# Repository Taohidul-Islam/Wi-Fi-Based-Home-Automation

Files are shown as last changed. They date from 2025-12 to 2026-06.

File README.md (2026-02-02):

# Wi-Fi-Based-Home-Automation
<h2>This Board can turn any regular household electric switchboard into a smart Wi-Fi and Remote controlled switchboard.</h2>
<p>Here the board I designed is fail protected, meaning even if my electronic logic fails, the switchboard would work like a regular switchboard. The Automation Board is designed maintaining hierarchy. Meaning the Automation Board can only work only if the main switch from switch board is set to "on". In my logic I don't really turn anything "On". Everything is default "On" and "Off" by switchboard. I can just turn the things "Off" when the switch is "On" by triggering relay and turn the things back to it's default "On" position</p>
<p>N.B. IR remote control is currently unavailable and AC induction fan control channel can be faulty as it is not tested(will test soon).</p>

<P>Here are some screenshots of my PCB And Schematics</P>



Screenshot (96)
Screenshot (97)
Screenshot (98)
Screenshot (99)
Screenshot (116)
Screenshot (117)
Screenshot (118)
Screenshot (119)
Screenshot (120)

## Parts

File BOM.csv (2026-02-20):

Product | Value | Required Unit | Minimum Buying Unit | Buying Unit | Minimum buying unit Price(BDT) | Total Byuing Unit Price(Excluding Shipping)(BDT) | Total Byuing Unit Price(Excluding Shipping)(USD) | URL | Shipping From | Shipping Charge(BDT) | Shipping Charge(USD) | TOTAL COST AFTER SHIPPING(USD)
20 W Adapter | 220V AC--->5V DC | 1 | 1 | 1 | 1000 | 1000 | 8.09 | https://www.daraz.com.bd//products/i564440666-s2604870783.html?urlFlag=true | Daraz BD | 916 | 7.44 | 98.73
Relay Module | 5V Trigger, 10A 250VAC | 15 | 1 | 15 | 45 | 675 | 5.52 | https://www.daraz.com.bd//products/i319719106-s1469791008.html?urlFlag=true | Ali Express | 122.96 | 1.01
Fuse1 | 1A 5*20mm fast blow | 3 | set of 10 | 10 | 49 | 49 | 0.4 | https://www.daraz.com.bd//products/i444232118-s2128683451.html?urlFlag=true | Robotics BD | 55 | 0.45 | TOTAL COST AFTER SHIPPING(BDT)
Fuse2 | 2A 5*20mm fast blow | 12 | set of 10 | 20 | 49 | 98 | 0.8 | https://www.daraz.com.bd//products/i444232118-s2128683451.html?urlFlag=true | JLC PCB | 2166.41 | 17.73 | 12035.83
Fuse Holder | 5*20mm | 20 | set of10 | 20 | 49 | 49 | 0.4 | https://www.daraz.com.bd//products/i207310529-s1156909193.html?urlFlag=true | Printing Legion | 1596 | 13
PCB |  | 1 | 5 | 5 | 3580.46 | 3580.46 | 29.3 | https://trade.jlcpcb.com/checkout/payMethod/?unionSettleId=2c1f0726be4245ee9c5634154f041633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
Micro-Controller Board | ESP-32 Devkit k | 1 | 1 | 1 | 454 | 454 | 3.72 | https://www.daraz.com.bd//products/i324430221-s1552746576.html?urlFlag=true
Terminal Screw Blocks1 | P5mm 2pin | 12 | set of 5 | 15 | 37 | 111 | 0.91 | https://www.daraz.com.bd//products/i148914119-s1075120819.html?urlFlag=true
Terminal Screw Blocks2 | P5mm 3pin | 3 | set of 5 | 5 | 67 | 67 | 0.55 | https://www.daraz.com.bd//products/i295982132-s1309673742.html?urlFlag=true
Capacitor1 | 4.7uf-400V | 2 | set of 2 | 2 | 99 | 99 | 0.81 | https://www.daraz.com.bd//products/i458506660-s2198029867.html?urlFlag=true
Capacitor2 | 2.2uf-400V | 2 | set of 2 | 2 | 99 | 99 | 0.81 | https://www.daraz.com.bd//products/i535851508-s2573957824.html?urlFlag=true
Capacitor3 | 0.1uf-400V | 4 | set of 5 | 5 | 100 | 100 | 0.82 | https://www.daraz.com.bd//products/i128672154-s1048506248.html?urlFlag=true
Resistor1 | 220k 2W | 4 | set of 10 | 10 | 58 | 58 | 0.43 | https://www.daraz.com.bd//products/i286246768-s1284307192.html?urlFlag=true
Resistor2 | 2.2E 1/2W | 4 | set of 25 | 25 | 44 | 44 | 0.36 | https://www.daraz.com.bd//products/i143596114-s1067934018.html?urlFlag=true
Resistor3 | 220E 2W | 4 | set of 25 | 25 | 90 | 90 | 0.74 | https://www.daraz.com.bd//products/i225287965-s1170568856.html?urlFlag=true
Resistor4 | 2.2E 2W | 4 | Set of 20 | 20 | 120 | 120 | 0.98 | https://www.aliexpress.com/item/1005009970275128.html?mp=1
Varistor | 10D511k MOV | 4 | Set of 20 | 20 | 262 | 262 | 2.14 | https://www.aliexpress.com/item/1005010129610021.html?mp=1
Transistor Array | ULN2803A | 3 | 1 | 3 | 30 | 90 | 0.98 | https://store.roboticsbd.com/analog-ics-/1425-uln2803a-driver-ic-robotics-bangladesh.html
IR reciever module | vs1838B | 2 | 1 | 2 | 45 | 90 | 0.98 | https://www.daraz.com.bd//products/i227060729-s1171325043.html?urlFlag=true
Button | Push Buttons | 2 | Set of 3 | 3 | 44 | 44 | 0.36 | https://www.daraz.com.bd//products/i265246999-s1236615166.html?urlFlag=true
3D printing | Printing Legion Shipping | 1 | 1 | 1 | 0 | 0 | 0
TOTAL COST |  |  |  |  |  | 7179.46 | 59.1 |  |  | 4856.37 | 39.63

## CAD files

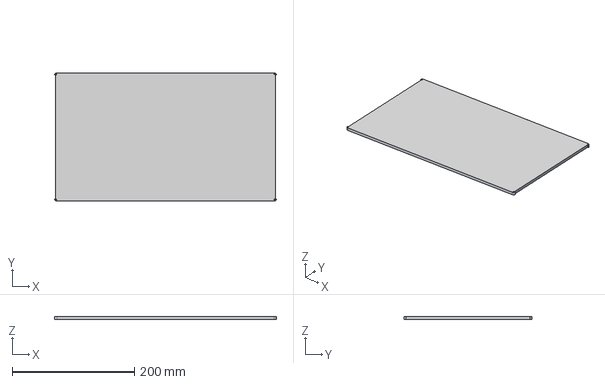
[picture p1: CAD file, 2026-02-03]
3D Model/HomeAutomationCaseLID3mm.step
363.0 x 210.0 x 5.00 mm

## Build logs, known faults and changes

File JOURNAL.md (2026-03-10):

<h1>Learned How to Design a PCB</h1>
<h2>December 11, 2025</h2>
<h3>Spent time: 2.8Hours</h3>
<p>Today through youtube, I learned how to design a PCB on Kikad and started building my first PCB design. Before I worked with breadboard circuitry but never designed a PCB. The one I am designing right now is not related to any project. It's just an tutorial piece. I am gonna make my main project PCB next day. The whole circuitry is on my head right now.
</p>




<h1>Completed my first PCB</h1>
<h2>December 12, 2025</h2>
<h3>Spent time:2.5Hours</h3>
<p>Today I completed my basic learning on building PCB and built an mini inverter PCB watching a tutorial. I leant how to make Gerber file and what to send to PCB manufacturer to manufacture my PCB. I hope from the next day, I can start building my project PCB.
</p>



<h1>Started making Schematics, researched on how to control AC.</h1>
<h2>December 13, 2025</h2>
<h3>Spent time: 4 Hours</h3>
<p> Today I started building my project PCB and done research on how to control AC average voltage with a TRIAC and ESP 32. I want to make a board which can be attached to any switch board and turn it into a smart switchboard. I want to also want to put an AC induction fan regulator. That's why I needed to learn about Triacs. But controlling AC voltage without a transformer is pretty hard ngl. Bought some things to practically learn about TRIACS.
</p>
Today I started building my project PCB and done research on how to control AC average voltage with a TRIAC and ESP 32. Bought some things to practically learn about TRIACS.




<h1>Finished doing Schematics</h1>
<h2>December 15, 2025</h2>
<h3>Spent time: 8 Hours</h3>
<p>I am journaling after two days as I was busy researching on how to control AC voltage via ESP 32. I couldn't get the TRIACS work so I switched to capacitor based step regulator. And after calculating my preferences and everything it took me a lot of time to do the schematics properly. I used a lot of labels as so many wirings might make it look messy. I switched to the capacitor method cause that is mostly traditional and many people used this kind off setup before me. I failed in controlling TRIACS on my demo model, so I gave up on it and switched to Capacitor based voltage control for AC induction FAN.</p>


<h1>Modified Schematics for safety</h1>
<h2>December 17, 2025</h2>
<h3>Spent time: 5 Hours</h3>
<p> Modified my final schematics to make it safe and sustainable against AC currents. Did a lot of research on making it safe and placed apropiate safety measures. I mainly added fused to each Channel so if anything inside the circuit failed, the board doesn't become a fire hazard. I also tried to put some place for Varistors for overvoltage protection. I want my board to be like this that if it fails due to any circumstances, the main switch board works perfectly fine.
 </p>




<h1>Started Designing PCB</h1>
<h2>December 18, 2025</h2>
<h3>Spent time: 2.5 Hours</h3>
<p>I started to design PCB today. First I assigned footprint to all of the components and started making PCB design. Researched how to put it on right place and decided where to put which components and started doing it. I wanted to complete routing today but couldn't due to limited time. I want to make it as compact as possible while maintaining the board design easy to understand and use, so anyone can do the wirings smoothly. So I needed to do put all screw terminal on a single side. But I did a silly mistake. In the 3d model, the screw hole was faced inward but I wanted it to be outward. Because the problem was with only 3D model and the routing can't be neater by putting the terminal to the expected side, I chose to keep the the 3D model as it is. While putting together the components, I just have to flip the terminals and that solves everything. I couldn't edit the 3d model as it was flipping the terminal and ruining my routing blueprint.</p>


<h1>Routed the PCB and Completed the hardware part.</h1>
<h2>December 22, 2025</h2>
<h3>Spent Time: 8 Hours</h3>
<p>Today I completed all my work of hardware on Kikad. I completed my PCB designing ensuring no error persisted. I checked it many times and found flaws until it showed no errors. I fixed all my errors and flaws and made it a workable PCB. I suffered a lot while choosing apropiate size for my paths in PCB, so I asked Gemini and gave him a list of what voltage and what current I want to use in what path, he suggested some width but I used a little bit more width than recommended because it gives a bit more headroom. While filling the PCB to GND, I kept all the AC traces away from the fill to prevent and leakage. Adjusting gap from pad to fill took a lot of time. I forgot that I increased the global distance from pad to fill a lot and was trying to adjust the distance in my tab so that wasn't working. After hours of not noticing it, I finally remembered that my global value was high. Then I decreased the global value and after that I could adjust my project value. Sometimes small silly things take more time than important things. Placing Via connection on right place with right radius and padding was also a bit tricky. I avoided via on high voltage AC side. I am very happy today.
</p>





<h1>Completed the coding part.</h1>
<h2>December 23, 2025</h2>
<h3>Spent time: 4 Hours</h3>
<p>
Today I wrote whole logic of my my system and used AI to code more efficiently. I tested all logics by lighting LED and ensuring signal is going properly wherever is need. The logic is like this,
Default, Switch On and Switch On means Low signal doing nothing. This will allow the NC gate of relay to work perfectly without interacting with the microcontroller.
Then when I press the switch On, microcontroller pin gives High signal which is transmitted to ULN transistor array that pulls the negative side of relay coil to ground thus activating the relay and turning the device off.
The fan regulator one is pretty complex. There is normal On off for fan with no Capacitor adjustment. but if you want, after turning off that normal on off button, you can turn on regulated switch buttons, which can channel electricity from 3 types of capacitor and resistor arrangements and controlling the fans speed within 3 Level.
After powering on the microcontroller, the microcontroller works as an Wi-Fi AP(Access Point) and after connecting to it's wifi network and going to certain IP, we can control the devices by toggling graphical toggle switch within phone browser. And there is a option to put home Wi-Fi SSID and password to connect it to home Wi-Fi and make it accessible from anyone in the Wi-Fi network. That is currently in Wi-Fi LAN but it is possible to put it to WAN through port forwarding if you have a real IP, that is a bit complicated and not suitable for everyone. I am planning to develop an application software to control it without typing IPs and using Browsers.
I currently didn't put any IR control code as I never worked with IR receiver. So I left a place on PCB to put IR receiver so after I learn about it, I can add it. This would make the thing more versatile by not depending only on WI-Fi Communications.
</p>


<h1>Enriched Journal Entries and BOM</h1>
<h2>January 14, 2026</h2>
<h3>Spent 2.5 Hours</h3>
<p>After getting reviewed by blueprint team, I needed to convert BOM from BDT to USD and to add more information on Journal. And for cost efficiency I needed to choose E-Post delivery on JLC PCB, SO I did that. Today I did nothing but edit BOM, rewriting some journal entries and take checkout screenshots.
I needed to convert USD to BDT and BDT simultaneously with cent accuracy, because I had a lot of components which had prices under a dollar. And due to BDT to USD price fluctuation and inflation, my prices decreased a little bit. I also added shipping charge separately site by site.</p>


<h1>Updated BOM again</h1>
<h2>February 1, 2026</h2>
<h3>Spent 1 Hour</h3>
<p>After getting reviewed again, I had to change the BOM again to remove the tools I mentioned there. So the cost got a bit low. I also got suggestion on how to make the schematics a bit better and was suggested to make a case for my PCB. But as per I has near to no experience in CAD, learning it would take time, and that's the thing I have least right now. As per my SSC examination(Comparable to O level) is coming close, my parents aren't allowing much screen time, so I couldn't make any larger changes. Changing schematics would require me to re-route the whole PCB, which would take hours. But as far I checked with many AI tools, my project seems to be functional. And as per I am new to PCB designing I might have broken some conventions while designing the PCB. Still I am trying if I can make a simple case.
</p>


<h1>Making Case For the PCB</h1>
<h2>February 2, 2026</h2>
<h3>Spent 4 Hours</h3>
<p>Today I somehow managed some time to make an case for my PCB in fusion 360. Learning this software was not that easy. Whatever, the hardest part was to figure out how to put the PCB from kikad into the case in fusion 360. After wandering for 30 minutes I figured it out and made a step file of my pcb from kikad first then imported that step into my fusion 360. now it looks pretty good. I also put screw holes to assemble it.
</p>
Screenshot (120)
Screenshot (119)
Screenshot (118)
Screenshot (117)
Screenshot (116)

<h1>Edited the case</h1>
<h2>March 11, 2026</h2>
<h3>Spent 2 Hours</h3>
<p>Today I added standoffs to my existing case to make my PCB secure inside the case. Previously I added just screw holes which might have been a trouble as the pins of pcb might get damaged by the case. Now it is fine with standoffs.</p>
Screenshot (124)

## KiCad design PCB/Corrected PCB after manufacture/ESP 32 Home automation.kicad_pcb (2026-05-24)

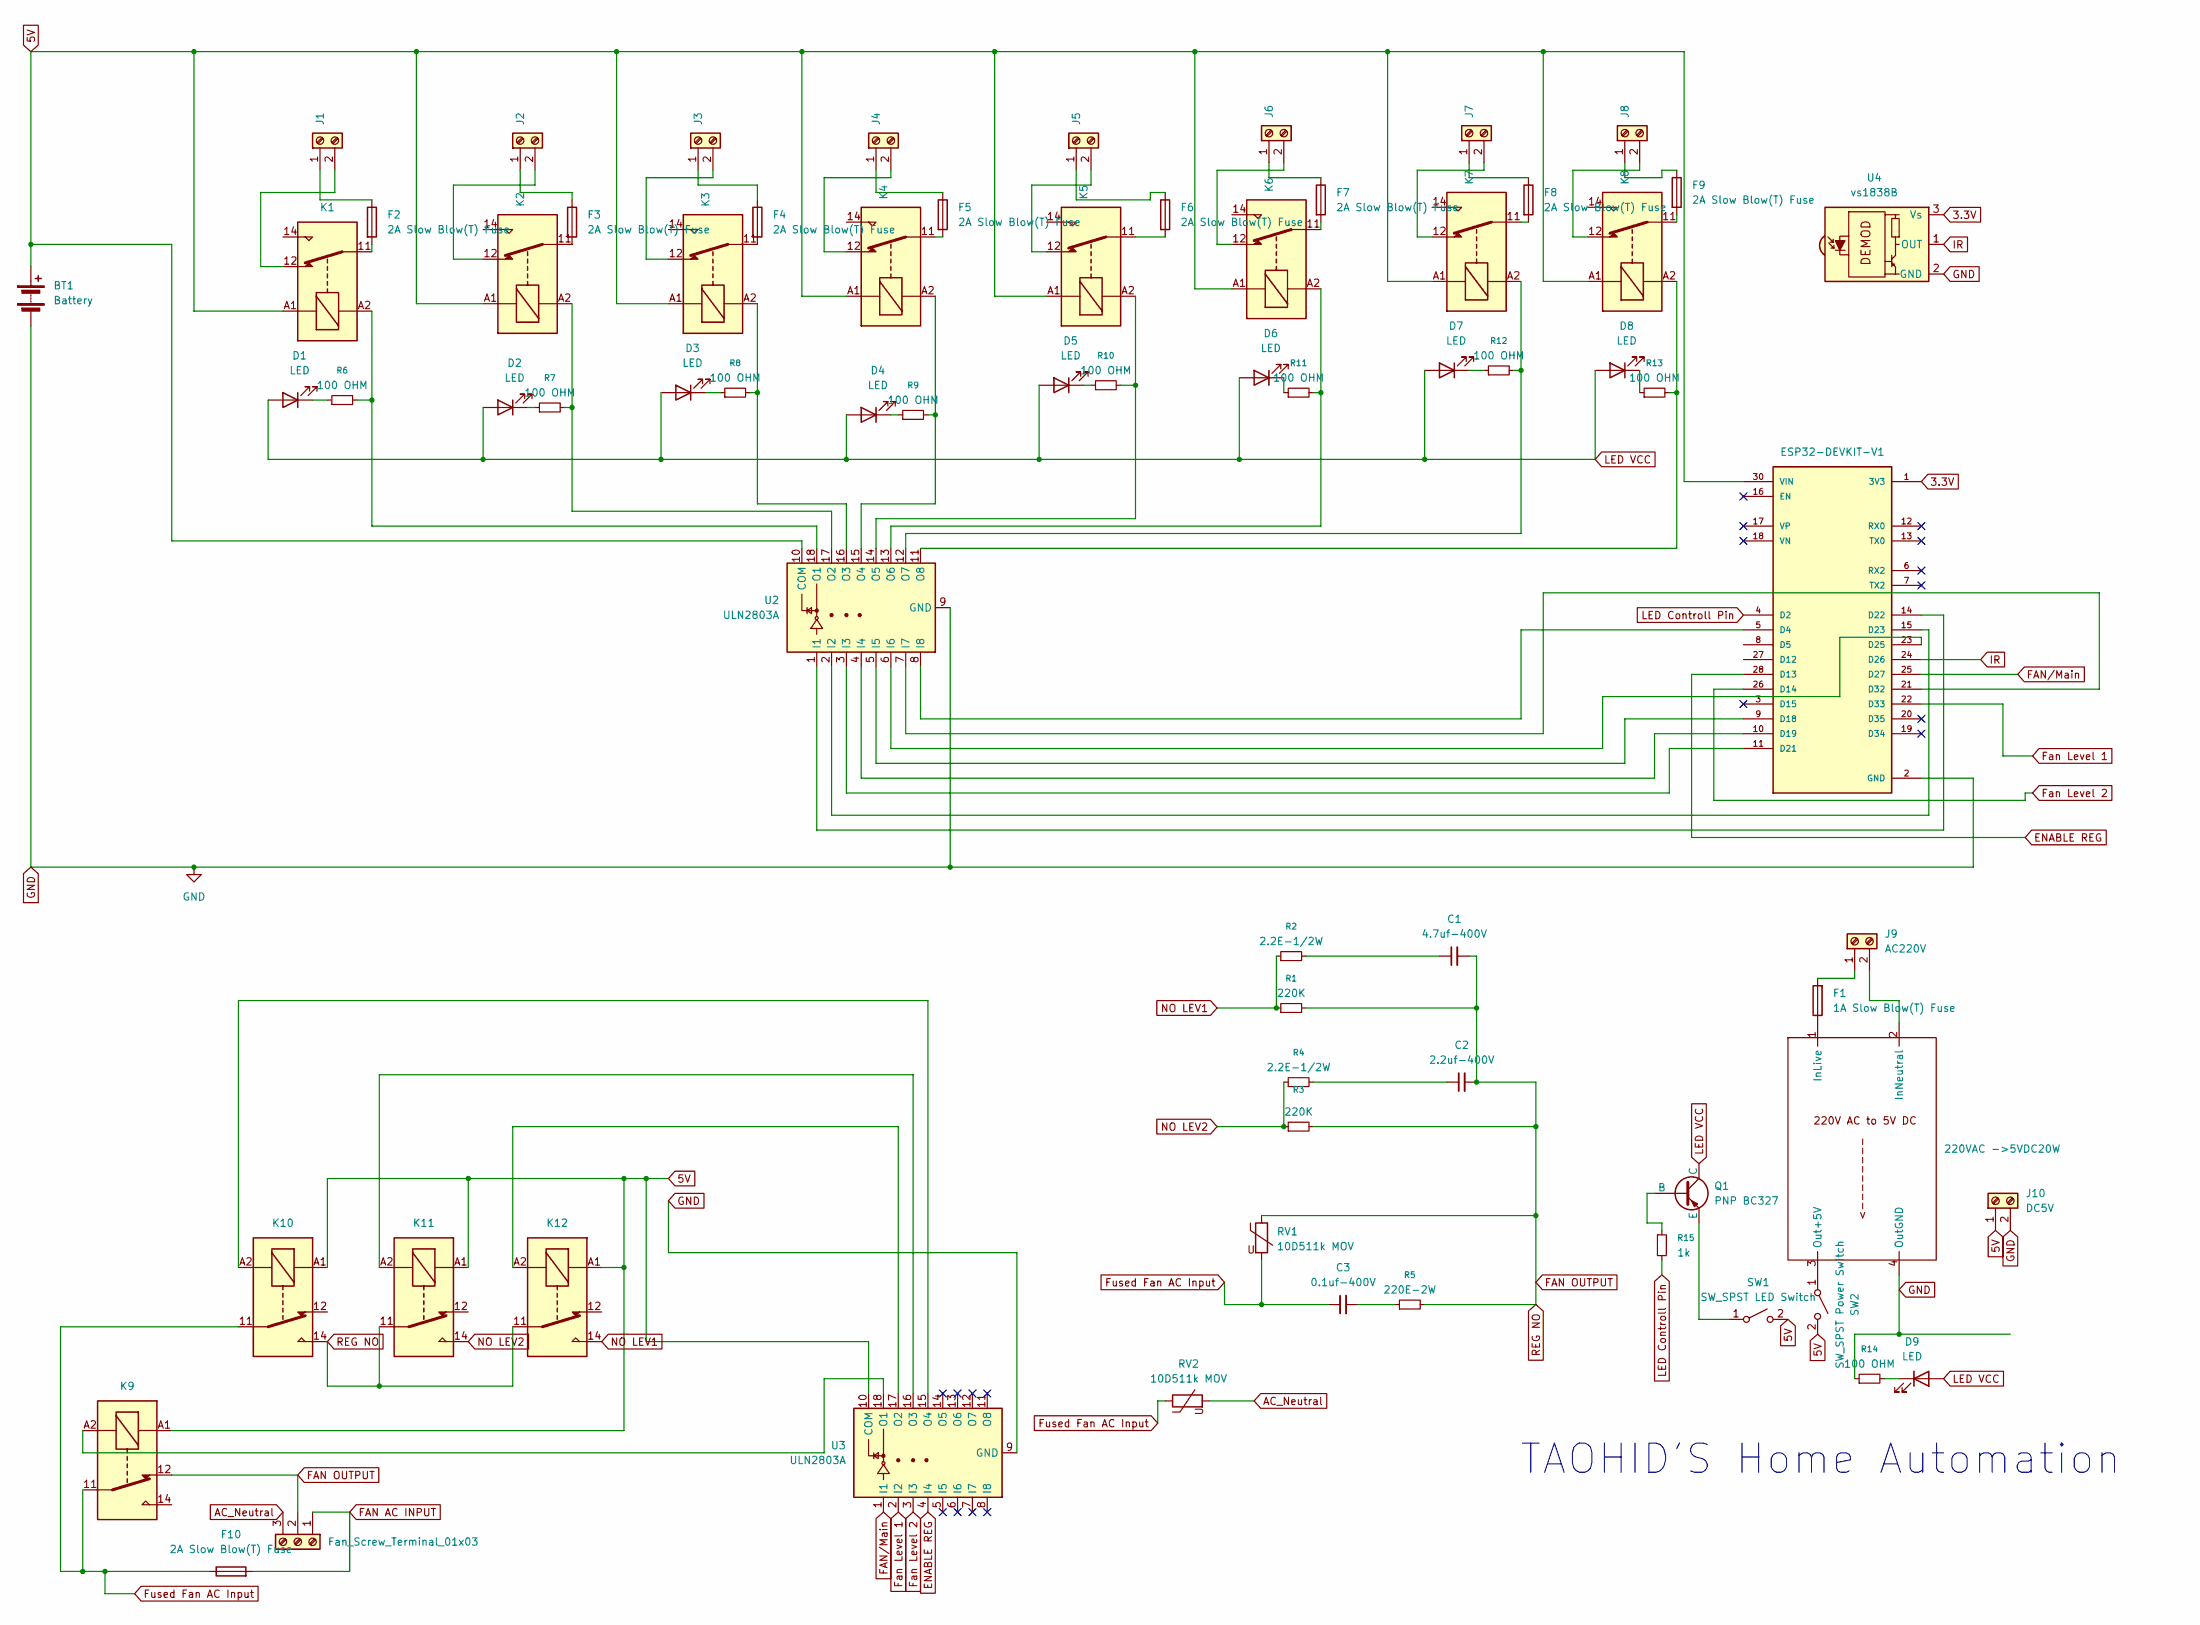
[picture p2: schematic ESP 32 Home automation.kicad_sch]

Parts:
Adapter/Charger1: 220VAC ->5VDC20W; ACtoDC power Adapter. 220V to 5V
BT1: Battery; TerminalBlock_MaiXu_MX126-5.0-02P_1x02_P5.00mm
C1: 4.7uf-400V; C_Rect_L32.0mm_W15.0mm_P27.00mm
C2: 2.2uf-400V; C_Rect_L27.0mm_W9.0mm_P22.00mm
C3: 0.1uf-400V; C_Rect_L13.0mm_W6.5mm_P7.50mm_P10.00mm
D1, D2, D3, D4, D5, D6, D7, D8, D9: LED; LED_D5.0mm
F1: 1A Slow Blow(T) Fuse; Fuseholder_Littelfuse_100_series_5x20mm
F2, F3, F4, F5, F6, F7, F8, F9, F10: 2A Slow Blow(T) Fuse; Fuseholder_Littelfuse_100_series_5x20mm
J1, J2, J3, J4, J5, J6, J7, J8: Screw_Terminal_01x02; TerminalBlock_Phoenix_MKDS-1,5-2-5.08_1x02_P5.08mm_Horizont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
J9: AC220V; TerminalBlock_Phoenix_MKDS-1,5-2-5.08_1x02_P5.08mm_Horizont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
J10: DC5V; TerminalBlock_Phoenix_MKDS-1,5-2-5.08_1x02_P5.08mm_Horizont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
J11: Fan_Screw_Terminal_01x03; TerminalBlock_Phoenix_MKDS-1,5-3-5.08_1x03_P5.08mm_Horizont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
K1, K2, K3, K4, K5, K6, K7, K8, K9, K10, K11, K12: JQC-3FF-005-1Z; Relay_SPDT_Hongfa_JQC-3FF_0XX-1Z
Q1: PNP BC327; TO-92_Inline
R1, R3: 220K; R_Axial_DIN0309_L9.0mm_D3.2mm_P20.32mm_Horizontal
R2, R4: 2.2E-1/2W; R_Axial_DIN0309_L9.0mm_D3.2mm_P20.32mm_Horizontal
R5: 220E-2W; R_Axial_DIN0309_L9.0mm_D3.2mm_P20.32mm_Horizontal
R6, R7, R8, R9, R10, R11, R12, R13, R14: 100 OHM; R_Axial_DIN0207_L6.3mm_D2.5mm_P7.62mm_Horizontal
R15: 1k; R_Axial_DIN0207_L6.3mm_D2.5mm_P7.62mm_Horizontal
RV1, RV2: 10D511k MOV; RV_Disc_D12mm_W7.5mm_P7.5mm
SW1: SW_SPST LED Switch; TerminalBlock_Phoenix_MKDS-1,5-2_1x02_P5.00mm_Horizontal
SW2: SW_SPST Power Switch; TerminalBlock_Phoenix_MKDS-1,5-2_1x02_P5.00mm_Horizontal
U1: ESP32-DEVKIT-V1; MODULE_ESP32_DEVKIT_V1; PARTREV N/A
U2, U3: ULN2803A; DIP-18_W7.62mm_Socket_LongPads
U4: vs1838B; Vishay_MOLD-3Pin

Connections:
3.3V: U1.1 (3V3), U4.3 (Vs)
5V: BT1.1 (+), J10.1, K1.A1, K2.A1, K3.A1, K4.A1, K5.A1, K6.A1, K7.A1, K8.A1, K9.A1, K10.A1, K11.A1, K12.A1, SW1.2 (B), SW2.2 (B), U1.30 (VIN), U2.10 (COM), U3.10 (COM)
AC_Neutral: J11.3, RV2.2; also elsewhere on the board
ENABLE REG: U1.28 (D13), U3.4 (I4)
FAN AC INPUT: F10.2, J11.1
FAN/Main: U1.25 (D27), U3.1 (I1)
Fan Level 1: U1.22 (D33), U3.2 (I2)
Fan Level 2: U1.26 (D14), U3.3 (I3)
Fused Fan AC Input: C3.1, F10.1, K9.11, K10.11, RV1.2, RV2.1
GND: Adapter/Charger1.4 (OutGND), BT1.2 (-), J10.2, R14.1, U1.2 (GND), U1.29 (GND), U2.9 (GND), U3.9 (GND), U4.2 (GND)
IR: U1.24 (D26), U4.1 (OUT)
LED Controll Pin: R15.2, U1.4 (D2)
LED VCC: D1.2 (A), D2.2 (A), D3.2 (A), D4.2 (A), D5.2 (A), D6.2 (A), D7.2 (A), D8.2 (A), D9.2 (A), Q1.1 (C)
NO LEV1: K12.14, R1.1, R2.1
NO LEV2: K11.14, R3.1, R4.1
unnamed: Adapter/Charger1.1 (InLive), F1.1
unnamed: Adapter/Charger1.2 (InNeutral), J9.2
unnamed: Adapter/Charger1.3 (Out+5V), SW2.1 (A)
unnamed: C1.1, R2.2
unnamed: C2.1, R4.2
unnamed: C3.2, R5.1
unnamed: D2.1 (K), R7.1
unnamed: D3.1 (K), R8.1
unnamed: D4.1 (K), R9.1
unnamed: D5.1 (K), R10.1
unnamed: D6.1 (K), R11.1
unnamed: D7.1 (K), R12.1
unnamed: D8.1 (K), R13.1
unnamed: D9.1 (K), R14.2
unnamed: F2.2, K1.11
unnamed: F3.2, K2.11
unnamed: F4.2, K3.11
unnamed: F5.2, K4.11
unnamed: F6.2, K5.11
unnamed: F7.2, K6.11
unnamed: F8.2, K7.11
unnamed: F9.2, K8.11
unnamed: F2.1, J1.1
unnamed: J1.2, K1.12
unnamed: F3.1, J2.1
unnamed: J2.2, K2.12
unnamed: F4.1, J3.1
unnamed: J3.2, K3.12
unnamed: F5.1, J4.1
unnamed: J4.2, K4.12
unnamed: F6.1, J5.1
unnamed: J5.2, K5.12
unnamed: F7.1, J6.1
unnamed: J6.2, K6.12
unnamed: F8.1, J7.1
unnamed: J7.2, K7.12
unnamed: F9.1, J8.1
unnamed: J8.2, K8.12
unnamed: F1.2, J9.1
unnamed: Q1.2 (B), R15.1
unnamed: Q1.3 (E), SW1.1 (A)
unnamed: U1.5 (D4), U2.8 (I8)
unnamed: U1.9 (D18), U2.5 (I5)
unnamed: U1.10 (D19), U2.4 (I4)
unnamed: U1.11 (D21), U2.3 (I3)
unnamed: U1.14 (D22), U2.1 (I1)
unnamed: U1.15 (D23), U2.2 (I2)
unnamed: U1.23 (D25), U2.6 (I6)
unnamed: U1.21 (D32), U2.7 (I7)
unnamed: K2.A2, R7.2, U2.17 (O2)
unnamed: K3.A2, R8.2, U2.16 (O3)
unnamed: K4.A2, R9.2, U2.15 (O4)
unnamed: K5.A2, R10.2, U2.14 (O5)
unnamed: K6.A2, R11.2, U2.13 (O6)
unnamed: K7.A2, R12.2, U2.12 (O7)
unnamed: K8.A2, R13.2, U2.11 (O8)
unnamed: K9.A2, U3.18 (O1)
unnamed: K12.A2, U3.17 (O2)
unnamed: K11.A2, U3.16 (O3)
unnamed: K10.A2, U3.15 (O4)

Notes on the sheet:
TAOHID'S Home Automation

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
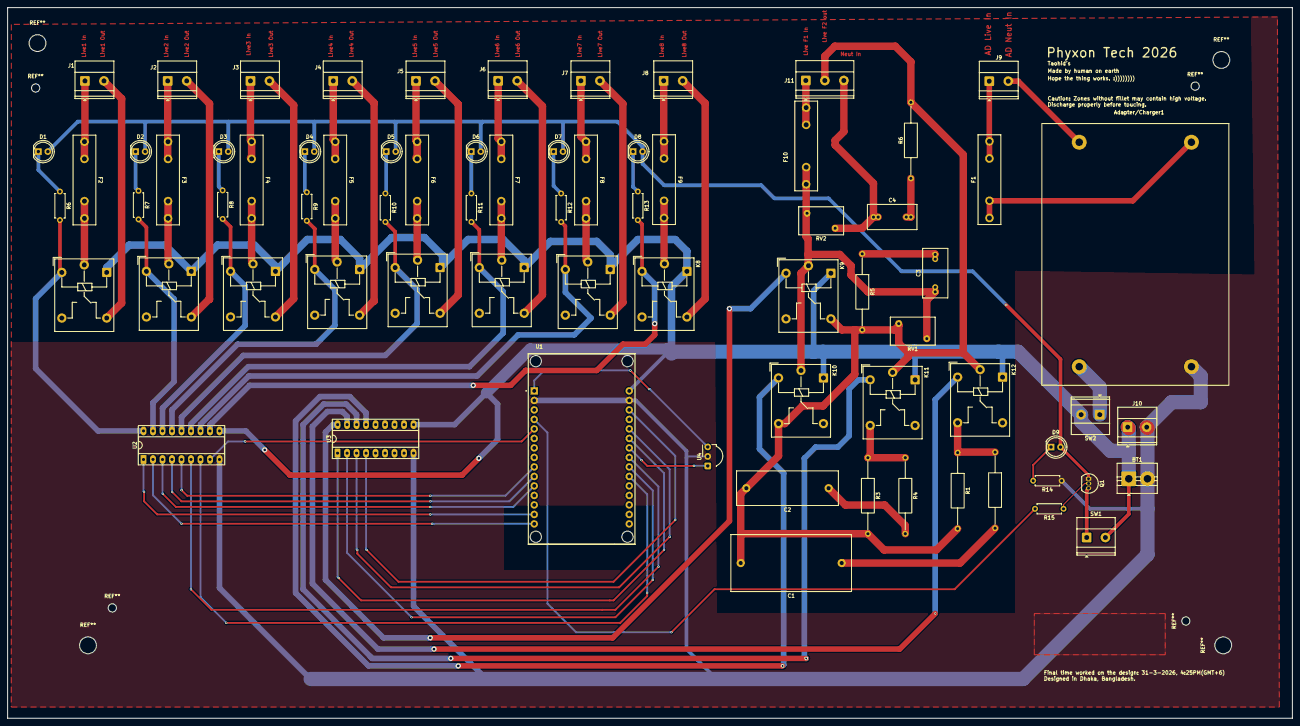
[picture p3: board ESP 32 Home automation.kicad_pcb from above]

Board: 2 copper layers, 343.5 x 190.0 mm, 73 parts (0 on the bottom side), 79 nets.

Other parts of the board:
C4: 0.1uf-400V; C_Rect_L13.0mm_W6.5mm_P7.50mm_P10.00mm
R6#2: 100 OHM; R_Axial_DIN0207_L6.3mm_D2.5mm_P7.62mm_Horizontal

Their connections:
AC_Neutral: C4.1; also elsewhere on the board

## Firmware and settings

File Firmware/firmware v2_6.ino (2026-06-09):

/*
 * ============================================================
 *   Wi-Fi Based Automation Firmware v2.6
 *   by Taohid | Phyxon Tech
 *   Board: DOIT ESP32 DevKit V1
 *   Change Line 113 and 504 as per your credentials
 * ============================================================
 *
 * Required Libraries (install via Arduino Library Manager):
 *   - IRremote (by Armin Joachimsmeyer) >= 4.x
 *   - U8g2 (by oliver)
 *   - ArduinoJson (by Benoit Blanchon) >= 6.x
 *   - NewPing (by Tim Eckel)
 *
 * Changes in v2.6:
 *   - IR I button: decrease people count (min 0)
 *   - IR J button: increase people count
 *   - IR K button: factory reset (moved from J)
 * ============================================================
 * GPIO TABLE:
 *   RELAY_1=22, RELAY_2=23, RELAY_3=21, RELAY_4=19
 *   RELAY_5=18, RELAY_6=25, RELAY_7=32, RELAY_8=4
 *   RESET_PIN=15  (INPUT_PULLUP, pull to GND = factory reset)
 *   LED_CTRL=2    (PNP driver, LOW=LEDs ON)
 *   LED_BTN=14    (OUTPUT HIGH after boot, pull to GND = toggle LED)
 *   IR_RECV=26
 *   OLED_SDA=27, OLED_SCL=33
 *   SONAR1_TRIG=5,  SONAR1_ECHO=34  (outside doorframe)
 *   SONAR2_TRIG=12, SONAR2_ECHO=35  (inside doorframe)
 * ============================================================
 */

#include <WiFi.h>
#include <WebServer.h>
#include <Preferences.h>
#include <ESPmDNS.h>
#include <HTTPClient.h>
#include <HTTPUpdate.h>
#include <ArduinoJson.h>
#include <Wire.h>
#include <U8g2lib.h>
#include <IRremote.hpp>
#include <NewPing.h>
#include <time.h>
#include <math.h>

// ============================================================
// GPIO
// ============================================================
#define RELAY_1      22
#define RELAY_2      23
#define RELAY_3      21
#define RELAY_4      19
#define RELAY_5      18
#define RELAY_6      25
#define RELAY_7      32
#define RELAY_8       4
#define RESET_PIN    15
#define LED_CTRL      2
#define LED_BTN      14
#define IR_RECV_PIN  26
#define OLED_SDA     27
#define OLED_SCL     33
#define SONAR1_TRIG   5
#define SONAR1_ECHO  34
#define SONAR2_TRIG  12
#define SONAR2_ECHO  35
#define SONAR_MAX_DIST 200

// ============================================================
// IR CODES
// ============================================================
#define IR_1     0x01
#define IR_2     0x02
#define IR_3     0x03
#define IR_4     0x04
#define IR_5     0x05
#define IR_6     0x06
#define IR_7     0x07
#define IR_8     0x08
#define IR_9     0x09
#define IR_0     0x00
#define IR_PWR   0x12
#define IR_A     0x14
#define IR_B     0x10
#define IR_C     0x16
#define IR_D     0x0C
#define IR_E     0x49
#define IR_H     0x0F
#define IR_I     0x45
#define IR_J     0x56
#define IR_K     0x5C
#define IR_OK    0x0E
#define IR_UP    0x1B
#define IR_DOWN  0x1F
#define IR_LEFT  0x1E
#define IR_RIGHT 0x1A
#define IR_SLASH 0x0B

// ============================================================
// NETWORK
// ============================================================
const char* ap_ssid     = "ESP32_SmartSwitch";
const char* ap_password = "12345678";
IPAddress ap_ip(192, 168, 4, 1);
IPAddress ap_gateway(192, 168, 4, 1);
IPAddress ap_subnet(255, 255, 255, 0);
IPAddress static_ip(192, 168, 0, 200);
IPAddress gateway_ip(192, 168, 0, 1);
IPAddress subnet_ip(255, 255, 255, 0);
IPAddress dns_ip(192, 168, 0, 1);

const char* OTA_HOST   = "YOUR SERVER IP HERE";
const int   OTA_PORT   = 8080;
const char* FW_VERSION = "2.6";

// ============================================================
// OLED — SH1106 1.3" SW I2C, U8G2_R2 = 180° for upside-down mount
// ============================================================
U8G2_SH1106_128X64_NONAME_F_SW_I2C u8g2(U8G2_R2, OLED_SCL, OLED_SDA, U8X8_PIN_NONE);

// ============================================================
// SONARS
// ============================================================
NewPing sonar1(SONAR1_TRIG, SONAR1_ECHO, SONAR_MAX_DIST);
NewPing sonar2(SONAR2_TRIG, SONAR2_ECHO, SONAR_MAX_DIST);

// ============================================================
// SCREEN IDs
// ============================================================
#define SCREEN_WEATHER   0
#define SCREEN_EYES      1
#define SCREEN_CLOCK     2
#define SCREEN_ANALOG    3
#define SCREEN_OVERVIEW  4
#define SCREEN_WEBUI     5
#define SCREEN_PEOPLE    6
#define SCREEN_COUNT     7

// ============================================================
// EYE SYSTEM
// ============================================================
#define LEX    34
#define REX    94
#define EYE_CY 30
#define EW     28
#define EH     36
#define ER     10

enum Emotion {
  EMO_FRONT=0, EMO_BLINK, EMO_SLEEP, EMO_HAPPY,
  EMO_MAD, EMO_CRY, EMO_CONFUSED, EMO_TIRED,
  EMO_WIDE, EMO_NIGHT, EMO_COUNT
};

Emotion currentEmo = EMO_FRONT;
unsigned long emoStart = 0;
int emoSeqIdx = 0;
float pupilX = 0, pupilY = 0, pupilTX = 0, pupilTY = 0;
unsigned long lastPupilPick = 0;

Emotion emoSequence[] = {
  EMO_FRONT, EMO_BLINK, EMO_FRONT, EMO_HAPPY,
  EMO_FRONT, EMO_BLINK, EMO_MAD,   EMO_FRONT,
  EMO_CRY,   EMO_FRONT, EMO_TIRED, EMO_BLINK,
  EMO_WIDE,  EMO_FRONT, EMO_CONFUSED, EMO_FRONT,
  EMO_SLEEP, EMO_FRONT, EMO_NIGHT, EMO_FRONT
};
const int emoSeqLen = 20;
unsigned long emoDurations[] = {
  2500,400,2000,1500,2000,400,1800,1500,
  2000,1500,1800,400,1200,2000,2000,2000,
  2500,1500,2000,2000
};

// ============================================================
// WEATHER
// ============================================================
struct Weather {
  String description;
  float  temp=0; int humidity=0;
  bool   isCloudy=false; bool fetched=false;
};
Weather wx;
unsigned long lastWeatherFetch=0;
float cloudOffset=0; unsigned long lastCloudUpdate=0;
#define WEATHER_INTERVAL 600000UL

// ============================================================
// GLOBAL STATE
// ============================================================
WebServer   server(80);
Preferences preferences;

bool relayStates[8]      = {false};
bool ledState             = true;
const int relayPins[8]   = {RELAY_1,RELAY_2,RELAY_3,RELAY_4,RELAY_5,RELAY_6,RELAY_7,RELAY_8};

bool   useAPMode    = true;
String storedSSID   = "";
String storedPass   = "";

bool   darkMode         = true;
String weatherCity      = "Dhaka";
int    timezone_offset  = 6;

bool   autoOffEnabled[8]      = {false};
int    peopleCount             = 1;
bool   sonarActive             = false;
bool   autoOffedByPresence[8] = {false};

int    autoOffDelaySec  = 0;   // seconds to wait before turning off on zero count
int    autoOnDelaySec   = 0;   // seconds to wait before turning on when count goes 0→1+

// Timer state for delayed actions
bool          pendingOff        = false;
unsigned long pendingOffTime    = 0;
bool          pendingOn         = false;
unsigned long pendingOnTime     = 0;

bool   screenEnabled[SCREEN_COUNT];
int    screenInterval       = 5;
bool   autoSwitch           = true;
int    currentScreen        = SCREEN_EYES;
int    fixedScreen          = SCREEN_EYES;
int    screenBeforeWebUI    = SCREEN_EYES;

bool   oledInWebUI  = false;
int    oledTab      = 0;
int    oledCursor   = 0;

bool   showingStartupIP = true;
unsigned long startupIPTime = 0;
#define STARTUP_IP_DURATION 10000UL

unsigned long lastOLEDDraw   = 0;
#define OLED_REFRESH_MS 30

unsigned long lastScreenSwitch = 0;
unsigned long ledBtnLastPress  = 0;
#define DEBOUNCE_MS 200

int    sonarDetectDist  = 60;    // cm — configurable from web settings
int    sonarConfirmWin  = 1500;  // ms — tightened for 15cm doorframe

// Alternating fire state
int    sonarTurn        = 0;     // 0=fire S1, 1=fire S2
unsigned long lastSonarFire = 0;
#define SONAR_FIRE_INTERVAL 50   // ms between alternate pings

unsigned long sonar1TrigTime=0, sonar2TrigTime=0;
bool sonar1Triggered=false, sonar2Triggered=false;

// Cooldown after crossing
#define SONAR_COOLDOWN 2500
unsigned long lastCrossingTime=0;

// Live state for web dots
bool sonar1Live=false, sonar2Live=false;
unsigned long sonar1LiveTime=0, sonar2LiveTime=0;
#define SONAR_LIVE_DISPLAY_MS 400

// FreeRTOS sonar task handle
TaskHandle_t sonarTaskHandle = NULL;
// Mutex to protect shared sonar state accessed from both cores
portMUX_TYPE sonarMux = portMUX_INITIALIZER_UNLOCKED;

String otaStatusMsg = "";

// ============================================================
// FORWARD DECLARATIONS
// ============================================================
void initGPIO(); void applyAllStates();
void startAPMode(); void connectToWiFi();
void setupRoutes(); void factoryReset();
void fetchWeather(); void syncNTP(); void doOTAUpdate();
void sonarTask(void* pvParameters);
void handleLEDButton(); void handleIR();
void drawOLED();
void drawWeather(); void drawEyes(); void drawDigitalClock();
void drawAnalogClock(); void drawOverview(); void drawWebUI();
void drawPeople(); void drawStartupIP();
void nextEnabledScreen(); void centreStr(const char* s, int y);
String buildHomePage(); String buildSettingsPage(); String buildStatusJSON();
void saveSettings(); void loadSettings();
void fillEye(int cx,int cy,int w,int h,int r);
void drawPupil(int cx,int cy,int px,int py,int pr);
void drawEyeWithLid(int cx,int cy,float close,bool upperOnly);
void drawEmo_Front(); void drawEmo_Blink(float t); void drawEmo_Sleep();
void drawEmo_Happy(); void drawEmo_Mad(); void drawEmo_Cry(float t);
void drawEmo_Confused(); void drawEmo_Tired(); void drawEmo_Wide(); void drawEmo_Night();
void drawSunIcon(int cx,int cy); void drawCloudIcon(int cx,int cy);
void handleToggle(); void handleToggleLed(); void handleSaveWiFi();
void handleUseAP(); void handleSaveSettings(); void handleSetPeople();

// ============================================================
// SETUP
// ============================================================
void setup() {
  Serial.begin(115200); delay(500);
  Serial.println("\n=== Phyxon Home Automation v2.1 ===");

  pinMode(LED_BTN, OUTPUT);
  digitalWrite(LED_BTN, HIGH);

  Wire.begin(OLED_SDA, OLED_SCL);
  u8g2.begin();
  u8g2.setContrast(220);

  preferences.begin("phyxon", false);
  loadSettings();
  for(int i=0;i<SCREEN_COUNT;i++)
    screenEnabled[i] = preferences.getBool(("se"+String(i)).c_str(), true);

  initGPIO();
  applyAllStates();

  sonarActive = false;
  for(int i=0;i<8;i++) if(autoOffEnabled[i]) { sonarActive=true; break; }

  // Always start sonar task on Core 0 (for people counting even without auto-off)
  xTaskCreatePinnedToCore(sonarTask, "SonarTask", 4096, NULL, 1, &sonarTaskHandle, 0);

  IrReceiver.begin(IR_RECV_PIN, DISABLE_LED_FEEDBACK);

  if(!useAPMode && storedSSID.length()>0) connectToWiFi();
  else startAPMode();

  if(MDNS.begin("phyxon")) Serial.println("mDNS: phyxon.local");
  setupRoutes();
  server.begin();

  if(WiFi.getMode()==WIFI_STA && WiFi.status()==WL_CONNECTED) {
    syncNTP(); fetchWeather();
  }

  showingStartupIP = true;
  startupIPTime    = millis();
  emoStart         = millis();
  randomSeed(millis());
  Serial.println("=== Ready ===");
}

// ============================================================
// LOOP
// ============================================================
void loop() {
  server.handleClient();
  handleLEDButton();
  handleIR();

  // Delayed auto-off: fire if timer expired and count still zero
  if(pendingOff && peopleCount == 0 &&
     millis() - pendingOffTime >= (unsigned long)(autoOffDelaySec * 1000)) {
    pendingOff = false;
    for(int i=0;i<8;i++) if(autoOffEnabled[i] && relayStates[i]) {
      relayStates[i]=false; digitalWrite(relayPins[i],HIGH);
      preferences.putBool(("r"+String(i)).c_str(),false);
      autoOffedByPresence[i]=true;
    }
    Serial.println("Delayed OFF executed");
  }
  // Cancel pending off if someone came back
  if(pendingOff && peopleCount > 0) {
    pendingOff = false;
    Serial.println("Pending OFF cancelled, room occupied");
  }

  // Delayed auto-on: fire if timer expired and count still > 0
  if(pendingOn && peopleCount > 0 &&
     millis() - pendingOnTime >= (unsigned long)(autoOnDelaySec * 1000)) {
    pendingOn = false;
    for(int i=0;i<8;i++) if(autoOffedByPresence[i]) {
      relayStates[i]=true; digitalWrite(relayPins[i],LOW);
      preferences.putBool(("r"+String(i)).c_str(),true);
      autoOffedByPresence[i]=false;
    }
    Serial.println("Delayed ON executed");
  }
  // Cancel pending on if everyone left again
  if(pendingOn && peopleCount == 0) {
    pendingOn = false;
    Serial.println("Pending ON cancelled, room empty");
  }

  if(millis()-lastOLEDDraw > OLED_REFRESH_MS) {
    lastOLEDDraw=millis(); drawOLED();
  }

  if(autoSwitch && !oledInWebUI && !showingStartupIP) {
    if(millis()-lastScreenSwitch > (unsigned long)(screenInterval*1000)) {
      lastScreenSwitch=millis(); nextEnabledScreen();
    }
  }

  if(WiFi.status()==WL_CONNECTED && millis()-lastWeatherFetch>WEATHER_INTERVAL)
    fetchWeather();

  if(digitalRead(RESET_PIN)==LOW) { delay(50); if(digitalRead(RESET_PIN)==LOW) factoryReset(); }

  if(showingStartupIP && millis()-startupIPTime>STARTUP_IP_DURATION)
    showingStartupIP=false;
}

// ============================================================
// GPIO
// ============================================================
void initGPIO() {
  for(int i=0;i<8;i++) pinMode(relayPins[i],OUTPUT);
  pinMode(RESET_PIN,INPUT_PULLUP);
  pinMode(LED_CTRL,OUTPUT);
}
void applyAllStates() {
  for(int i=0;i<8;i++) digitalWrite(relayPins[i], relayStates[i]?LOW:HIGH);
  digitalWrite(LED_CTRL, ledState?LOW:HIGH);
}

// ============================================================
// WIFI
// ============================================================
void startAPMode() {
  WiFi.mode(WIFI_AP);
  WiFi.softAPConfig(ap_ip,ap_gateway,ap_subnet);
  WiFi.softAP(ap_ssid,ap_password);
  Serial.println("AP @ 192.168.4.1");
}
void connectToWiFi() {
  WiFi.mode(WIFI_STA);
  WiFi.config(static_ip,gateway_ip,subnet_ip,dns_ip);
  WiFi.begin(storedSSID.c_str(),storedPass.c_str());
  Serial.print("Connecting");
  int att=0;
  while(WiFi.status()!=WL_CONNECTED && att<30) { delay(500); Serial.print("."); att++; }
  if(WiFi.status()==WL_CONNECTED) Serial.println("\nConnected: "+WiFi.localIP().toString());
  else { Serial.println("\nFailed, fallback AP"); startAPMode(); }
}

// ============================================================
// SETTINGS
// ============================================================
void loadSettings() {
  storedSSID     = preferences.getString("ssid","");
  storedPass     = preferences.getString("pass","");
  useAPMode      = preferences.getBool("useAP",true);
  ledState       = preferences.getBool("led",true);
  darkMode       = preferences.getBool("dark",true);
  weatherCity    = preferences.getString("city","Dhaka");
  timezone_offset= preferences.getInt("tz",6);
  peopleCount    = preferences.getInt("people",1);
  autoSwitch     = preferences.getBool("autoSw",true);
  screenInterval = preferences.getInt("scrInt",5);
  fixedScreen    = preferences.getInt("fixedScr",SCREEN_EYES);
  currentScreen  = autoSwitch ? SCREEN_EYES : fixedScreen;
  sonarDetectDist= preferences.getInt("snrDist", 60);
  sonarConfirmWin= preferences.getInt("snrWin",  2000);
  autoOffDelaySec= preferences.getInt("aoDelay", 0);
  autoOnDelaySec = preferences.getInt("aonDelay",0);
  for(int i=0;i<8;i++) {
    relayStates[i]   = preferences.getBool(("r"+String(i)).c_str(),false);
    autoOffEnabled[i]= preferences.getBool(("ao"+String(i)).c_str(),false);
  }
}
void saveSettings() {
  preferences.putBool("useAP",useAPMode); preferences.putBool("led",ledState);
  preferences.putBool("dark",darkMode);   preferences.putString("city",weatherCity);
  preferences.putInt("tz",timezone_offset); preferences.putInt("people",peopleCount);
  preferences.putBool("autoSw",autoSwitch); preferences.putInt("scrInt",screenInterval);
  preferences.putInt("fixedScr",fixedScreen);
  preferences.putInt("snrDist", sonarDetectDist);
  preferences.putInt("snrWin",  sonarConfirmWin);
  preferences.putInt("aoDelay", autoOffDelaySec);
  preferences.putInt("aonDelay",autoOnDelaySec);
  for(int i=0;i<8;i++) {
    preferences.putBool(("r"+String(i)).c_str(),relayStates[i]);
    preferences.putBool(("ao"+String(i)).c_str(),autoOffEnabled[i]);
  }
  for(int i=0;i<SCREEN_COUNT;i++)
    preferences.putBool(("se"+String(i)).c_str(),screenEnabled[i]);
}
void factoryReset() {
  Serial.println("FACTORY RESET");
  preferences.clear(); delay(500); ESP.restart();
}

// ============================================================
// NTP
// ============================================================
void syncNTP() {
  configTime(timezone_offset*3600,0,"pool.ntp.org","time.nist.gov");
  Serial.print("NTP sync");
  struct tm t; int tr=0;
  while(!getLocalTime(&t)&&tr<20){delay(500);Serial.print(".");tr++;}
  Serial.println(getLocalTime(&t)?" OK":" FAIL");
}

// ============================================================
// WEATHER
// ============================================================
void fetchWeather() {
  if(WiFi.status()!=WL_CONNECTED) return;
  lastWeatherFetch=millis();
  HTTPClient http;
  String url="http://api.openweathermap.org/data/2.5/weather?q="+
             weatherCity+"&appid=YOURAPIKEYHERE&units=metric";
  http.begin(url); http.setTimeout(8000);
  if(http.GET()==200) {
    String payload=http.getString();
    JsonDocument doc;
    if(!deserializeJson(doc,payload)) {
      wx.temp       =doc["main"]["temp"].as<float>();
      wx.humidity   =doc["main"]["humidity"].as<int>();
      wx.description=doc["weather"][0]["description"].as<String>();
      wx.isCloudy   =(String(doc["weather"][0]["main"].as<const char*>())!="Clear");
      wx.fetched    =true;
      Serial.printf("Weather:%.1fC %d%% %s\n",wx.temp,wx.humidity,wx.description.c_str());
    }
  }
  http.end();
}

// ============================================================
// OTA (manual trigger from web button)
// ============================================================
void doOTAUpdate() {
  if(WiFi.status()!=WL_CONNECTED) { otaStatusMsg="No WiFi"; return; }
  otaStatusMsg="Checking server...";
  HTTPClient http;
  http.begin("http://"+String(OTA_HOST)+":"+String(OTA_PORT)+"/version");
  int code=http.GET();
  if(code!=200) { otaStatusMsg="Server unreachable (HTTP "+String(code)+")"; http.end(); return; }
  String sv=http.getString(); sv.trim(); http.end();
  if(sv==String(FW_VERSION)) { otaStatusMsg="Already up to date (v"+String(FW_VERSION)+")"; return; }
  otaStatusMsg="Updating to v"+sv+"...";
  saveSettings();
  String binUrl="http://"+String(OTA_HOST)+":"+String(OTA_PORT)+"/firmware.bin";
  WiFiClient client;
  t_httpUpdate_return ret=httpUpdate.update(client, binUrl);
  switch(ret) {
    case HTTP_UPDATE_FAILED:    otaStatusMsg="Failed: "+httpUpdate.getLastErrorString(); break;
    case HTTP_UPDATE_NO_UPDATES:otaStatusMsg="No updates found"; break;
    case HTTP_UPDATE_OK:        otaStatusMsg="Updated! Rebooting..."; break;
  }
}

// ============================================================
// LED BUTTON
// ============================================================
void handleLEDButton() {
  pinMode(LED_BTN,INPUT);
  bool pressed=(digitalRead(LED_BTN)==LOW);
  pinMode(LED_BTN,OUTPUT); digitalWrite(LED_BTN,HIGH);
  if(pressed && millis()-ledBtnLastPress>DEBOUNCE_MS) {
    ledBtnLastPress=millis();
    ledState=!ledState;
    digitalWrite(LED_CTRL,ledState?LOW:HIGH);
    preferences.putBool("led",ledState);
  }
}
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

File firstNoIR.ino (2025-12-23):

#include <WiFi.h>
#include <WebServer.h>
#include <Preferences.h>
#include <ESPmDNS.h>

// GPIO Pin Definitions
#define RELAY_1 22
#define RELAY_2 23
#define RELAY_3 21
#define RELAY_4 19
#define RELAY_5 18
#define RELAY_6 25
#define RELAY_7 32
#define RELAY_8 4

#define FAN_ON 27
#define FAN_LEV1 33
#define FAN_LEV2 14
#define FAN_LEV3 13

#define RESET_PIN 15  // Reset to AP mode button (pull to GND)

// AP Mode Configuration
const char* ap_ssid = "ESP32_SmartSwitch";
const char* ap_password = "12345678";
IPAddress ap_ip(192, 168, 4, 1);
IPAddress ap_gateway(192, 168, 4, 1);
IPAddress ap_subnet(255, 255, 255, 0);

// Static IP Configuration for Home WiFi
IPAddress static_ip(192, 168, 0, 200); // Change this to your desired static IP
IPAddress gateway(192, 168, 0, 1);     // Your router's gateway
IPAddress subnet(255, 255, 255, 0);
IPAddress dns(192, 168, 0, 1);

// Global Variables
WebServer server(80);
Preferences preferences;

bool relayStates[8] = {true, true, true, true, true, true, true, true}; // Default ON
bool fanOnState = true;  // Default ON
int fanLevel = 0;        // 0=OFF, 1=LEV1, 2=LEV2, 3=LEV3
bool useAPMode = true;
String storedSSID = "";
String storedPassword = "";
unsigned long lastStatusPrint = 0;

// GPIO Pins Array
const int relayPins[8] = {RELAY_1, RELAY_2, RELAY_3, RELAY_4, RELAY_5, RELAY_6, RELAY_7, RELAY_8};

void setup() {
  Serial.begin(115200);
  delay(1000);
  
  Serial.println("\n\n========================================");
  Serial.println("   ESP32 Smart Switchboard v1.0");
  Serial.println("========================================\n");
  
  // Initialize Preferences
  preferences.begin("wifi-config", false);
  storedSSID = preferences.getString("ssid", "");
  storedPassword = preferences.getString("password", "");
  useAPMode = preferences.getBool("useAP", true);
  
  Serial.println("Stored SSID: " + (storedSSID.length() > 0 ? storedSSID : "None"));
  Serial.println("Use AP Mode: " + String(useAPMode ? "Yes" : "No"));
  
  // Load saved states
  for(int i = 0; i < 8; i++) {
    relayStates[i] = preferences.getBool(("relay" + String(i)).c_str(), true);
  }
  fanOnState = preferences.getBool("fanOn", true);
  fanLevel = preferences.getInt("fanLevel", 0);
  
  // Initialize GPIO Pins
  initGPIO();
  applyAllStates();
  
  Serial.println("\n--- Network Configuration ---");
  
  // Start WiFi
  if (!useAPMode && storedSSID.length() > 0) {
    connectToWiFi();
  } else {
    startAPMode();
  }
  
  // Setup Web Server Routes
  setupRoutes();
  server.begin();
  
  Serial.println("\n========================================");
  Serial.println("   System Ready!");
  Serial.println("========================================\n");
}

void loop() {
  server.handleClient();
  
  // Print status every 10 seconds if in WiFi mode
  if(WiFi.getMode() == WIFI_STA && millis() - lastStatusPrint > 10000) {
    lastStatusPrint = millis();
    Serial.println("\n--- Status Update ---");
    Serial.print("WiFi Connected: ");
    Serial.println(WiFi.status() == WL_CONNECTED ? "YES" : "NO");
    Serial.print("IP Address: ");
    Serial.println(WiFi.localIP());
    Serial.print("Access at: http://");
    Serial.println(WiFi.localIP());
    Serial.print("Or via: http://smartswitch.local");
    Serial.println("\n-------------------\n");
  }
  
  // Check if reset button is pressed (pulled to GND)
  if(digitalRead(RESET_PIN) == LOW) {
    delay(50); // Debounce
    if(digitalRead(RESET_PIN) == LOW) {
      Serial.println("Reset button pressed! Switching to AP mode...");
      
      // Save AP mode preference
      preferences.putBool("useAP", true);
      
      delay(500);
      ESP.restart();
    }
  }
}

void initGPIO() {
  // Initialize all relay pins
  for(int i = 0; i < 8; i++) {
    pinMode(relayPins[i], OUTPUT);
  }
  
  // Initialize fan control pins
  pinMode(FAN_ON, OUTPUT);
  pinMode(FAN_LEV1, OUTPUT);
  pinMode(FAN_LEV2, OUTPUT);
  pinMode(FAN_LEV3, OUTPUT);
  
  // Initialize reset button with internal pull-up
  pinMode(RESET_PIN, INPUT_PULLUP);
}

void applyAllStates() {
  // Apply relay states (ON = LOW, OFF = HIGH)
  for(int i = 0; i < 8; i++) {
    digitalWrite(relayPins[i], relayStates[i] ? LOW : HIGH);
  }
  
  // Apply fan states
  digitalWrite(FAN_ON, fanOnState ? LOW : HIGH);
  
  if(fanOnState) {
    // Fan is ON, disable all levels
    digitalWrite(FAN_LEV1, LOW);
    digitalWrite(FAN_LEV2, LOW);
    digitalWrite(FAN_LEV3, LOW);
  } else {
    // Fan is OFF, apply level if selected
    applyFanLevel();
  }
}

void applyFanLevel() {
  // First, turn off all levels with delay
  digitalWrite(FAN_LEV1, LOW);
  delay(50);
  digitalWrite(FAN_LEV2, LOW);
  delay(50);
  digitalWrite(FAN_LEV3, LOW);
  delay(50);
  
  // Then turn on the selected level (if any)
  if(fanLevel == 1) {
    digitalWrite(FAN_LEV1, HIGH);
  } else if(fanLevel == 2) {
    digitalWrite(FAN_LEV2, HIGH);
  } else if(fanLevel == 3) {
    digitalWrite(FAN_LEV3, HIGH);
  }
}

void startAPMode() {
  Serial.println("Starting AP Mode...");
  WiFi.mode(WIFI_AP);
  WiFi.softAPConfig(ap_ip, ap_gateway, ap_subnet);
  WiFi.softAP(ap_ssid, ap_password);
  
  Serial.print("AP IP Address: ");
  Serial.println(WiFi.softAPIP());
  Serial.println("Connect to WiFi: " + String(ap_ssid));
  Serial.println("Navigate to: http://192.168.4.1");
}

void connectToWiFi() {
  Serial.println("Connecting to WiFi...");
  Serial.println("SSID: " + storedSSID);
  WiFi.mode(WIFI_STA);
  WiFi.config(static_ip, gateway, subnet, dns);
  WiFi.begin(storedSSID.c_str(), storedPassword.c_str());
  
  int attempts = 0;
  while (WiFi.status() != WL_CONNECTED && attempts < 30) {
    delay(500);
    Serial.print(".");
    attempts++;
  }
  
  if (WiFi.status() == WL_CONNECTED) {
    Serial.println("\nConnected to WiFi!");
    Serial.print("Static IP Address: ");
    Serial.println(WiFi.localIP());
    Serial.print("Gateway: ");
    Serial.println(WiFi.gatewayIP());
    Serial.print("Subnet: ");
    Serial.println(WiFi.subnetMask());
    Serial.print("DNS: ");
    Serial.println(WiFi.dnsIP());
    
    // Setup mDNS
    if(MDNS.begin("smartswitch")) {
      Serial.println("mDNS started: http://smartswitch.local");
    }
  } else {
    Serial.println("\n❌ Failed to connect to WiFi!");
    Serial.println("Reason: " + String(WiFi.status()));
    Serial.println("Falling back to AP Mode...");
    
    // Clear saved credentials and switch to AP mode
    preferences.putBool("useAP", true);
    startAPMode();
  }
}

void setupRoutes() {
  server.on("/", HTTP_GET, handleRoot);
  server.on("/config", HTTP_GET, handleConfig);
  server.on("/savewifi", HTTP_POST, handleSaveWiFi);
  server.on("/useap", HTTP_POST, handleUseAP);
  server.on("/toggle", HTTP_POST, handleToggle);
  server.on("/fanon", HTTP_POST, handleFanOn);
  server.on("/fanlevel", HTTP_POST, handleFanLevel);
  server.on("/status", HTTP_GET, handleStatus);
}
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

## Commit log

2025-12-24 Update BOM.csv with new product entries
    [BOM.csv]
2025-12-24 Update JOURNAL.md with project progress details
    Documented progress on project PCB, including research on TRIAC control, schematic modifications for safety, PCB design, routing completion, and coding.
2026-02-02 Rename HOME AUTOMATION CASE NO LID.step to HOME AUTOMATION CASE DISASSEMBLED NO LID.step
    [HOME AUTOMATION CASE DISASSEMBLED NO LID.step]
2026-02-20 Update and rename BOM1.csv to BOM.csv
    [BOM.csv]
2026-03-10 Document case modifications and PCB standoffs
    Added details about adding standoffs to the case for PCB security.
